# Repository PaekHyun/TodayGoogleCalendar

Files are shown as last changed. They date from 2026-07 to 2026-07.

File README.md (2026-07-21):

# Google Calendar → nanoESP32-C6 → WeAct 3.7" E-Paper

nanoESP32-C6에서 Google Calendar ICS를 가져와 WeAct 3.7인치 e-paper에 오늘 일정을 표시하는 프로젝트입니다.

## 사진

| 완성된 모습 | 동작 화면 |
|:---:|:---:|
| 완성된 모습 | 동작 화면 |

> 📸 사진을 추가하려면 `images/` 폴더에 이미지를 넣고 위 경로를 수정하세요.

## 하드웨어

| 부품 | 모델 |
|---|---|
| MCU | [nanoESP32-C6](https://github.com/wuxx/nanoESP32-C6) (MuseLab, ESP32-C6-WROOM-1) |
| 디스플레이 | WeAct 3.7" E-Paper Module (GDEY037T03, 240×416, UC8253) |
| 배터리 | 3.7V 리튬배터리 (10000mAh) |

## 배선도

```
nanoESP32-C6           WeAct 3.7" E-Paper
─────────────           ──────────────────
3V3            ──────→ VCC
GND            ──────→ GND
GPIO4  (MOSI)  ──────→ DIN (SDA/MOSI)
GPIO5  (SCK)   ──────→ CLK (SCK)
GPIO6  (CS)    ──────→ CS
GPIO7  (DC)    ──────→ DC
GPIO0  (RST)   ──────→ RST (RES)
GPIO1  (BUSY)  ──────→ BUSY
```

> **참고**: nanoESP32-C6는 ESP32-C6-WROOM-1 모듈 기반으로, GPIO 0~15, 18~21 등을 사용할 수 있습니다.
> GPIO12, GPIO13은 내부 플래시 접근용이므로 사용하지 마세요.

## 소프트웨어 설정

### 1. Arduino IDE 보드 설정

1. Arduino IDE → 파일 → 환경설정 → 추가 보드 매니저 URL:
   ```
   https://espressif.github.io/arduino-esp32/package_esp32_index.json
   ```
2. 툴 → 보드 → 보드 매니저 → `esp32` 검색 후 설치 (v2.0.8+)
3. 보드 선택: **ESP32C6 Dev Module**

### 2. 라이브러리 설치

Arduino IDE → 스케치 → 라이브러리 포함하기 → 라이브러리 관리:

| 라이브러리 | 작성자 | 용도 |
|---|---|---|
| **GxEPD2** | Jean-Marc Capello | E-Paper 디스플레이 드라이버 |
| **Adafruit GFX Library** | Adafruit | 그래픽 기반 라이브러리 |
| **U8g2_for_Adafruit_GFX** | Oliver | 한글 폰트 렌더링 |

### 3. WiFi 설정

`secrets.h` 파일을 열어 WiFi SSID와 비밀번호를 입력하세요:

```cpp
#define WIFI_SSID         "내WiFi이름"
#define WIFI_PASSWORD     "내WiFi비밀번호"
#define REFRESH_INTERVAL_MIN  30   // 새로고침 주기 (분)
```

### 4. 캘린더 설정

`TodayGoogleCalendar.ino` 상단의 `calendars[]` 배열에 Google Calendar 비공개 ICS URL을 입력하세요:

```cpp
CalendarInfo calendars[] = {
  { "가족", "https://calendar.google.com/calendar/ical/.../basic.ics" },
  { "시연", "https://calendar.google.com/calendar/ical/.../basic.ics" },
  { "정민", "https://calendar.google.com/calendar/ical/.../basic.ics" },
  { "현",   "https://calendar.google.com/calendar/ical/.../basic.ics" },
};
```

| 캘린더 인덱스 | 마커 |
|---|---|
| calendar[0] | ■ (꽉 찬 사각형) |
| calendar[1] | □ (빈 사각형) |
| calendar[2] | ▀ (위쪽 반) |
| calendar[3] | ▄ (아래쪽 반) |

### 5. 업로드

1. USB-C 케이블로 nanoESP32-C6 연결 (CH343 USB 포트 사용)
2. 올바른 포트 선택
3. 업로드 버튼 클릭

## 동작 흐름

```
부팅 → WiFi 연결(10초 타임아웃) → NTP 시간 동기화 → 
4개 캘린더 ICS 다운로드(5초 타임아웃) → 오늘 일정 파싱 → 
시간순 정렬 → E-Paper 표시 → WiFi OFF → E-Paper 전원차단 → 
GPIO 플로팅 방지 → 딥슬립 → N분 후 반복
```

## 절전 최적화

배터리 수명을 극대화하기 위해 다음 절전 기법이 적용되어 있습니다:

| 기법 | 설명 | 효과 |
|---|---|---|
| **딥슬립** | ESP32C6를 15μA 딥슬립 모드로 전환 | 대기 전류 ~99% 감소 |
| **WiFi 빠른 타임아웃** | 연결 10초, HTTP 5초로 단축 | 실패 시 낭비 전력 감소 |
| **WiFi 완전 해제** | 슬립 전 `WiFi.disconnect(true)` + `WIFI_OFF` | WiFi 모듈 누설 전류 차단 |
| **E-Paper RST LOW** | 슬립 중 RST 핀을 LOW로 전원 차단 | e-paper 누설 전류 감소 |
| **GPIO 풀다운** | 슬립 전 SPI/제어 핀 INPUT_PULLDOWN | 플로팅 핀 누설 전류 방지 |
| **전체 실패 시 즉시 슬립** | 4개 캘린더 모두 실패하면 바로 슬립 | 불필요한 WiFi 유지 방지 |

## 화면 레이아웃 (가로 모드 416×240)

```
┌──────────────────────────────────────────┐
│ 2026년 7월 15일 (수)                      │
│──────────────────────────────────────────│
│ 09:00-10:30  ■ 팀 미팅                    │
│              회의실 A                      │
│──────────────────────────────────────────│
│ 11:00-12:00  □ 시연 리허설                │
│──────────────────────────────────────────│
│ 종일         ▀ 생일 파티                   │
│──────────────────────────────────────────│
│ 14:00-15:30  ▄ 학원                       │
│                                          │
│                                          │
│ 11:28 갱신      ■가족 □시연 ▀정민 ▄현     │
└──────────────────────────────────────────┘
```

## 배터리 수명 (10000mAh 기준)

### 30분 주기 동작 사이클 전력 분석

| 구간 | 전류 | 시간 (초) | 비고 |
|---|---|---|---|
| WiFi 연결 | ~120mA | 5~8초 | AP 연결 + DHCP |
| NTP 동기화 | ~100mA | 2~3초 | |
| ICS 다운로드 ×4 | ~110mA | 10~20초 | HTTP GET ×4 |
| E-Paper 갱신 | ~30mA | 3~5초 | 화면 새로고침 |
| **활성 합계** | **~110mA** | **~30초** | |
| **딥슬립** | **~50~200μA** | **1790초** | e-paper 연결 누설포함 |

### 평균 소비 전류 계산

```
활성:  110mA × 30초  = 3,300 mA·s
슬립:  0.1mA × 1790초 =   179 mA·s  (딥슬립 100μA 가정)
─────────────────────────────────────
합계:  3,479 mA·s / 1800초 ≈ 1.93 mA (평균)
```

### 예상 수명

| 시나리오 | 딥슬립 전류 | 평균 소비 | 10000mAh 수명 |
|---|---|---|---|
| 🟢 이상적 | 15μA | ~1.85mA | **~225일 (7.5개월)** |
| 🟡 현실적 | 100μA | ~1.93mA | **~216일 (7.2개월)** |
| 🟠 보수적 | 500μA | ~2.14mA | **~195일 (6.5개월)** |
| 🔴 최악 | 1mA | ~2.83mA | **~147일 (4.9개월)** |

> 딥슬립 전류가 높아지는 주요 원인: e-paper 모듈의 풀업 저항 누설, WiFi 재시도, 배터리 보호 회로

### 현실적 결론

> **약 6~7개월** 동작 예상

단, 아래 요소를 고려하면 실제로는 **4~6개월** 정도로 보는 것이 안전합니다:

- 🔋 리튬배터리 방전 곡선 (3.7V → 3.0V 구간만 실사용 가능 → 유효 용량 ~85%)
- 📡 WiFi 연결 실패 시 재시도 (활성 시간 증가)
- 🌡️ 온도에 따른 배터리 효율 저하 (겨울철)
- ⚡ LDO 손실 (3.7V → 3.3V 변환 효율 ~90%)

### 💡 수명을 더 늘리려면

| 방법 | 효과 |
|---|---|
| 갱신 주기를 30분 → 1시간으로 | 수명 **약 1.8배** 연장 |
| ICS 다운로드 실패 시 즉시 슬립 ✅ | 불필요한 WiFi 유지 방지 (이미 적용) |
| E-Paper RST 핀으로 슬립 중 전원 차단 ✅ | 딥슬립 전류 50%↓ (이미 적용) |
| WiFi 연결 타임아웃 단축 (10초→5초) ✅ | 실패 시 낭비 감소 (이미 적용) |
| GPIO 플로팅 방지 ✅ | 누설 전류 감소 (이미 적용) |

## 문제 해결

| 증상 | 해결 방법 |
|---|---|
| 포트 인식 안 됨 | BOOT 버튼 누른 채 USB 연결 → 부트로더 모드 |
| WiFi 연결 실패 | SSID/비밀번호 확인, 2.4GHz 대역인지 확인 (5GHz 불가) |
| E-Paper 화면 안 나옴 | 배선 재확인, BUSY 핀 연결 상태 확인 |
| 시간 틀림 | NTP 서버 접근 가능한지 확인 |
| ICS 다운로드 실패 | ICS URL이 유효한지 브라우저에서 확인 |
| 배터리 빨리 닳음 | WiFi 타임아웃 확인, 딥슬립 진입 로그 확인 |

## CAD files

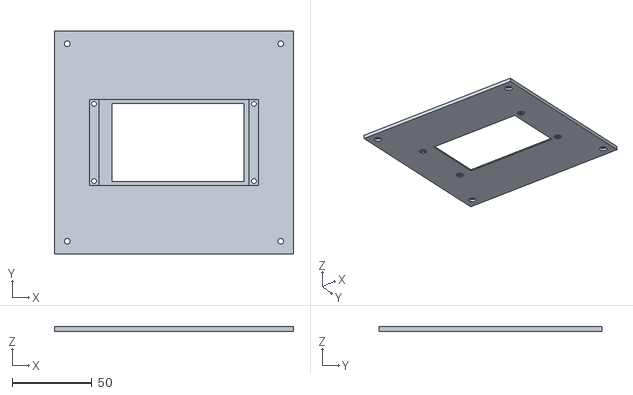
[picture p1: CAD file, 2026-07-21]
GoogleCalendarCase_FrontPanel.stl
150.0 x 140.0 x 3.00

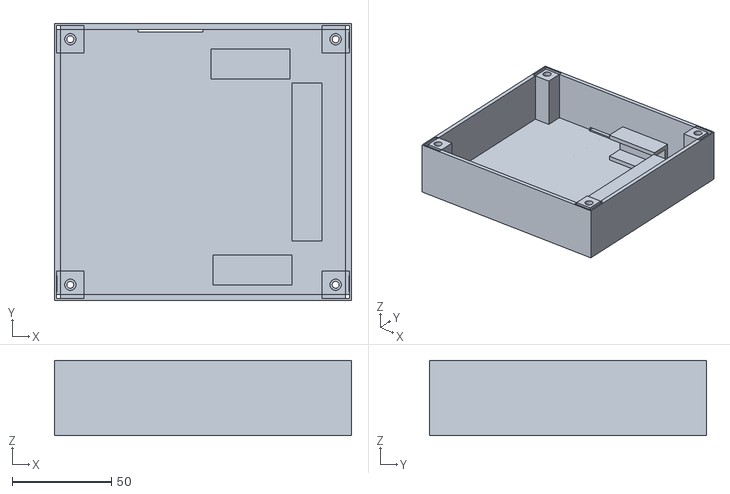
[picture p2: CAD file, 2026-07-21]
GoogleCalendar_RearPanel.stl
150.0 x 140.0 x 38.0

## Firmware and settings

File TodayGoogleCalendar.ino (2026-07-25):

/*
 * Google Calendar → nanoESP32-C6 → WeAct 3.7" E-Paper
 * 오늘 일정을 4개 캘린더에서 가져와 e-paper에 표시
 * 
 * 하드웨어 연결 (nanoESP32-C6 → e-paper):
 *   GPIO4  (MOSI) → DIN (SDA)
 *   GPIO5  (SCK)  → CLK (SCK)
 *   GPIO7  (DC)   → DC
 *   GPIO0  (RST)  → RST (RES)
 *   GPIO1  (BUSY) → BUSY
 *   GPIO6  (CS)   → CS
 *   3V3            → VCC
 *   GND            → GND
 * 
 * 필요 라이브러리:
 *   - GxEPD2 (by Jean-Marc Capello)
 *   - Adafruit_GFX
 *   - U8g2_for_Adafruit_GFX (by oliver)  ← 한글 폰트 지원
 * 
 * 보드 설정: ESP32C6 Dev Module (esp32 by Espressif v2.x+)
 * 보드: nanoESP32-C6 (MuseLab, https://github.com/wuxx/nanoESP32-C6)
 */

#define ENABLE_GxEPD2_GFX 0

#include <SPI.h>
#include <GxEPD2_BW.h>
#include <U8g2_for_Adafruit_GFX.h>  // 한글 폰트 지원

#include <WiFi.h>
#include <HTTPClient.h>
#include <time.h>

// ====== WiFi 설정 (secrets.h에서 수정) ======
#include "secrets.h"

// ====== 타임존 (KST = UTC+9) ======
const char* NTP_SERVER = "pool.ntp.org";
const long  TZ_OFFSET_SEC = 9 * 3600;   // UTC+9
const int   TZ_DST_SEC    = 0;

// ====== E-Paper 핀 설정 (nanoESP32-C6) ======
#define EPD_CS_PIN   6   // CS
#define EPD_DC_PIN   7   // DC
#define EPD_RST_PIN  0   // RST (RES)
#define EPD_BUSY_PIN 1   // BUSY
#define EPD_SCK_PIN  5   // SCK
#define EPD_MOSI_PIN 4   // MOSI (SDA/DIN)

#define VBAT_ADC_PIN        3      // 배터리 측정용 ADC 핀
#define VBAT_SAMPLES        8      // 평균낼 샘플 수
#define VBAT_DIVIDER_RATIO  2.0f   // 200kΩ : 200kΩ 분압


// [TestEPaper.ino 참고] 주석에 맞춰 핀 번호만 전달하여 객체 생성
GxEPD2_BW<GxEPD2_370_GDEY037T03, GxEPD2_370_GDEY037T03::HEIGHT> display(
  GxEPD2_370_GDEY037T03(EPD_CS_PIN, EPD_DC_PIN, EPD_RST_PIN, EPD_BUSY_PIN)
);

U8G2_FOR_ADAFRUIT_GFX u8g2Fonts; // 한글 폰트 렌더러

// ====== 캘린더 설정 ======
struct CalendarInfo {
  const char* name;
  const char* url;
};

CalendarInfo calendars[] = {
  { CAL_NAME_1, CAL_URL_1 },
  { CAL_NAME_2, CAL_URL_2 },
  { CAL_NAME_3, CAL_URL_3 },
  { CAL_NAME_4, CAL_URL_4 },
};
const int NUM_CALENDARS = sizeof(calendars) / sizeof(calendars[0]);

// ====== 일정 구조체 ======
struct Event {
  String summary;
  String location;
  int    startHour;
  int    startMin;
  int    endHour;
  int    endMin;
  bool   allDay;
  int    calIndex;
};

const int MAX_EVENTS = 30;
Event events[MAX_EVENTS];
int    eventCount = 0;

// ====== 캘린더 마커 그리기 ======
void drawCalMarker(int x, int y, int calIndex) {
  switch (calIndex % 4) {
    case 0: display.fillRect(x, y - 8, 6, 8, GxEPD_BLACK); break;  // ■ 꽉 찬 사각형
    case 1: display.drawRect(x, y - 8, 6, 8, GxEPD_BLACK); break;  // □ 빈 사각형
    case 2: display.fillRect(x, y - 8, 6, 4, GxEPD_BLACK); break;  // ▀ 위쪽 반
    case 3: display.fillRect(x, y - 4, 6, 4, GxEPD_BLACK); break;  // ▄ 아래쪽 반
  }
}

// ====== 배터리 전압 계산 ======
// VBAT --[200kΩ]-- ADC_PIN --[200kΩ]-- GND 형태의 분배 회로를 가정.
// analogReadMilliVolts()는 ESP32 코어에 내장된 ADC 보정(esp_adc_cal)을 사용하므로
// analogRead() 원시값을 직접 계산하는 것보다 정확합니다.
float readBatteryVoltage() {
  uint32_t sumMilliVolts = 0;
  for (int i = 0; i < VBAT_SAMPLES; i++) {
    sumMilliVolts += analogReadMilliVolts(VBAT_ADC_PIN);
    delay(1000);
  }
  float avgMilliVolts = (float)sumMilliVolts / VBAT_SAMPLES;
  float vbat = (avgMilliVolts / 1000.0f) * VBAT_DIVIDER_RATIO;

  Serial.printf("VBAT ADC 평균: %.1fmV -> 배터리 전압: %.2fV\n", avgMilliVolts, vbat);
  return vbat;
}

// ====== ICS 파싱 유틸리티 ======
void parseDateTime(const String& dtStr, int& year, int& month, int& day, int& hour, int& minute, bool& isAllDay) {
  isAllDay = false;
  year = 0; month = 0; day = 0; hour = 0; minute = 0;

  // 공백 및 앞뒤 잡음(개행문자 \r 등) 철저히 제거
  String cleanStr = dtStr;
  cleanStr.trim();
  cleanStr.replace("\r", "");
  cleanStr.replace("\n", "");

  if (cleanStr.length() == 8) {
    // 종일 일정 (예: 20260714)
    isAllDay = true;
    year  = cleanStr.substring(0, 4).toInt();
    month = cleanStr.substring(4, 6).toInt();
    day   = cleanStr.substring(6, 8).toInt();
  } 
  else if (cleanStr.length() >= 15) {
    // 일반 일정 (예: 20250210T073000Z)
    int tempYear  = cleanStr.substring(0, 4).toInt();
    int tempMonth = cleanStr.substring(4, 6).toInt();
    int tempDay   = cleanStr.substring(6, 8).toInt();
    int tempHour  = cleanStr.substring(9, 11).toInt();
    int tempMin   = cleanStr.substring(11, 13).toInt();

    if (cleanStr.endsWith("Z")) {
      struct tm t = {0};
      t.tm_year = tempYear - 1900;
      t.tm_mon  = tempMonth - 1;
      t.tm_mday = tempDay;
      t.tm_hour = tempHour + 9; // UTC -> KST (+9시간)
      t.tm_min  = tempMin;

      mktime(&t); 

      year   = t.tm_year + 1900;
      month  = t.tm_mon + 1;
      day    = t.tm_mday;
      hour   = t.tm_hour;
      minute = t.tm_min;
    } else {
      year   = tempYear;
      month  = tempMonth;
      day    = tempDay;
      hour   = tempHour;
      minute = tempMin;
    }
  }
}

int todayYear, todayMonth, todayDay;

void getToday() {
  struct tm timeinfo;
  if (!getLocalTime(&timeinfo)) {
    todayYear  = 2026; todayMonth = 7; todayDay = 14; // 폴백
    return;
  }
  todayYear  = timeinfo.tm_year + 1900;
  todayMonth = timeinfo.tm_mon + 1;
  todayDay   = timeinfo.tm_mday;
}

void parseICS(const String& icsData, int calIndex) {
  int pos = 0;
  while (pos < (int)icsData.length() && eventCount < MAX_EVENTS) {
    int veventStart = icsData.indexOf("BEGIN:VEVENT", pos);
    if (veventStart < 0) break;
    int veventEnd = icsData.indexOf("END:VEVENT", veventStart);
    if (veventEnd < 0) break;

    String vevent = icsData.substring(veventStart, veventEnd);


    String summary = "";
    String location = ""; 
    String dtStart = "";
    String dtEnd = "";

    // VEVENT 내부를 줄 단위로 분할하여 파싱
    int linePos = 0;
    while (linePos < (int)vevent.length()) {
      int nextLine = vevent.indexOf('\n', linePos);
      if (nextLine < 0) nextLine = vevent.length();
      
      String line = vevent.substring(linePos, nextLine);
      line.trim();
      line.replace("\r", ""); // \r 잔여물 제거

      if (line.startsWith("SUMMARY:")) {
        summary = line.substring(8);
      } else if (line.startsWith("LOCATION:")) {
        location = line.substring(9);
      } else if (line.startsWith("DTSTART")) {
        int colonIdx = line.indexOf(':');
        if (colonIdx >= 0) dtStart = line.substring(colonIdx + 1);
      } else if (line.startsWith("DTEND")) {
        int colonIdx = line.indexOf(':');
        if (colonIdx >= 0) dtEnd = line.substring(colonIdx + 1);
      }

      linePos = nextLine + 1;
    }

    // 앞뒤 공백 최종 트리밍
    summary.trim();
    location.trim();
    dtStart.trim();
    dtEnd.trim();

    int sYear, sMonth, sDay, sHour, sMin;
    bool sAllDay;
    parseDateTime(dtStart, sYear, sMonth, sDay, sHour, sMin, sAllDay);

    int eYear, eMonth, eDay, eHour, eMin;
    bool eAllDay;
    parseDateTime(dtEnd, eYear, eMonth, eDay, eHour, eMin, eAllDay);

    // [일정 판별 및 매칭]
    bool isToday = false;
    
    if (sAllDay) {
      if (sYear == todayYear && sMonth == todayMonth && sDay == todayDay) {
        isToday = true;
      }
      else if (sYear <= todayYear && eYear >= todayYear) {
        int todayScore = todayYear * 10000 + todayMonth * 100 + todayDay;
        int startScore = sYear * 10000 + sMonth * 100 + sDay;
        int endScore   = eYear * 10000 + eMonth * 100 + eDay;
        
        if (todayScore >= startScore && todayScore < endScore) {
          isToday = true;
        }
      }
    } else {
      if (sYear == todayYear && sMonth == todayMonth && sDay == todayDay) {
        isToday = true;
      }
    }

    if (isToday && summary.length() > 0) {
      events[eventCount].summary   = summary;
      events[eventCount].location  = location;
      events[eventCount].startHour = sHour;
      events[eventCount].startMin  = sMin;
      events[eventCount].endHour   = eHour;
      events[eventCount].endMin    = eMin;
      events[eventCount].allDay    = sAllDay;
      events[eventCount].calIndex  = calIndex;
      
      Serial.printf("  >> [추출성공] 캘린더[%d] | 일정: %s | 시작: %02d:%02d (종일: %s)\n", 
                    calIndex, summary.c_str(), sHour, sMin, sAllDay ? "예" : "아니오");

      eventCount++;

      delay(1000);
    } else {
      // 파싱 시도했으나 오늘 일정이 아닌 경우 디버그용 출력 (필요 시 주석 해제)
      // Serial.printf("  >> [패스] 일정: %s | 날짜: %04d-%02d-%02d\n", summary.c_str(), sYear, sMonth, sDay);
    }

    pos = veventEnd + 10;
  }
}

void sortEvents() {
  for (int i = 0; i < eventCount - 1; i++) {
    for (int j = i + 1; j < eventCount; j++) {
      int timeI = events[i].allDay ? -1 : events[i].startHour * 60 + events[i].startMin;
      int timeJ = events[j].allDay ? -1 : events[j].startHour * 60 + events[j].startMin;
      if (timeI > timeJ) {
        Event tmp = events[i];
        events[i] = events[j];
        events[j] = tmp;
      }
    }
  }
}



String fetchICS(const char* url) {
  HTTPClient http;
  String payload = "";

  http.setFollowRedirects(HTTPC_STRICT_FOLLOW_REDIRECTS);
  http.setTimeout(5000);
  http.setConnectTimeout(3000);

  if (http.begin(url)) {
    int httpCode = http.GET();
    if (httpCode == HTTP_CODE_OK) {
      payload = http.getString();
    } else {
      Serial.printf("[HTTP] GET → code: %d\n", httpCode);
    }
    http.end();
  } else {
    Serial.println("[HTTP] begin failed");
  }
  return payload;
}




// UTF-8 문자 경계를 지키면서, 주어진 픽셀 폭 안에 들어가도록 자르는 함수
String truncateToWidth(U8G2_FOR_ADAFRUIT_GFX& fonts, const String& text, int maxWidthPx) {
  if (fonts.getUTF8Width(text.c_str()) <= maxWidthPx) {
    return text;  // 안 잘라도 됨
  }

  String result = "";
  int i = 0;
  int len = text.length();

  while (i < len) {
    // 현재 문자의 바이트 길이 계산 (UTF-8 선두 바이트로 판별)
    unsigned char c = (unsigned char)text[i];
    int charLen = 1;
    if ((c & 0x80) == 0x00) charLen = 1;       // 0xxxxxxx: ASCII
    else if ((c & 0xE0) == 0xC0) charLen = 2;  // 110xxxxx
    else if ((c & 0xF0) == 0xE0) charLen = 3;  // 1110xxxx: 한글 대부분 여기
    else if ((c & 0xF8) == 0xF0) charLen = 4;  // 11110xxx

    if (i + charLen > len) break; // 깨진 데이터 방지

    String candidate = result + text.substring(i, i + charLen) + "..";
    if (fonts.getUTF8Width(candidate.c_str()) > maxWidthPx) {
      break; // "..." 붙였을 때 넘치면 여기서 멈춤
    }

    result += text.substring(i, i + charLen);
    i += charLen;
  }

  return result + "..";
}








// ====== E-Paper 표시 ======
void displayCalendar() {
  display.setRotation(1); // 가로 모드: 416 x 240
  display.setTextColor(GxEPD_BLACK);

  const int W = display.width();   // 416
  const int H = display.height(); // 240

  float vbatVoltage = readBatteryVoltage();

  display.setFullWindow();
  display.firstPage();
  do {
    display.fillScreen(GxEPD_WHITE);

    // ---- 헤더: 날짜 ----
    char dateStr[40];
    const char* dayNames[] = {"일", "월", "화", "수", "목", "금", "토"};
    struct tm timeinfo;
    getLocalTime(&timeinfo);
    snprintf(dateStr, sizeof(dateStr), "%d년 %d월 %d일 (%s)",
             todayYear, todayMonth, todayDay, dayNames[timeinfo.tm_wday]);

    u8g2Fonts.setFont(u8g2_font_unifont_t_korean2);
    u8g2Fonts.setCursor(8, 16);
    u8g2Fonts.print(dateStr);

    display.drawLine(0, 22, W, 22, GxEPD_BLACK);

    // ---- 일정 목록 ----
    int y = 38;
    const int lineHeight = 20;
    const int maxVisible = 8;

    if (eventCount == 0) {
      u8g2Fonts.setFont(u8g2_font_unifont_t_korean2);
      u8g2Fonts.setCursor(20, y + 10);
      u8g2Fonts.print("오늘 일정이 없습니다");
    } else {
      int showCount = min(eventCount, maxVisible);
      for (int i = 0; i < showCount; i++) {
        Event& ev = events[i];

        char timeBuf[20];
        if (ev.allDay) {
          snprintf(timeBuf, sizeof(timeBuf), "종일");
        } else {
          snprintf(timeBuf, sizeof(timeBuf), "%02d:%02d-%02d:%02d",
                   ev.startHour, ev.startMin, ev.endHour, ev.endMin);
        }


        u8g2Fonts.setFont(u8g2_font_unifont_t_korean2);

        // 시간 출력
        const int timeX = 4;
        u8g2Fonts.setCursor(timeX, y);
        u8g2Fonts.print(timeBuf);

        // 시간 문자열의 실제 폭 계산
        int timeWidth = u8g2Fonts.getUTF8Width(timeBuf);

        // 시간 뒤에 8픽셀 띄우고 마커 배치
        int markerX = timeX + timeWidth + 8;
        drawCalMarker(markerX, y, ev.calIndex);

        // 마커 뒤에 10픽셀 띄우고 제목 출력
        u8g2Fonts.setCursor(markerX + 10, y);

        int availWidth = W - (markerX + 10) - 4;
        String title = truncateToWidth(u8g2Fonts, ev.summary, availWidth);


        u8g2Fonts.print(title);



        if (ev.location.length() > 0 && y + 14 < H - 20) {
          u8g2Fonts.setCursor(92, y + 14);
          int availWidthLoc = W - 92 - 4;
          String loc = truncateToWidth(u8g2Fonts, ev.location, availWidthLoc);
          u8g2Fonts.print(loc);
          y += lineHeight + 14;
        } else {
          y += lineHeight;
        }

        if (i < showCount - 1 && y < H - 20) {
          // display.drawFastHLine(4, y - 4, W - 8, GxEPD_BLACK);
          display.drawFastHLine(4, y + 5, W - 8, GxEPD_BLACK);
        }
      }

      if (eventCount > maxVisible) {
        u8g2Fonts.setFont(u8g2_font_unifont_t_korean2);
        u8g2Fonts.setCursor(W - 80, H - 6);
        char moreBuf[20];
        snprintf(moreBuf, sizeof(moreBuf), "+%d개 더", eventCount - maxVisible);
        u8g2Fonts.print(moreBuf);
      }
    }

    // ---- 하단: 업데이트 시간 ----
    u8g2Fonts.setFont(u8g2_font_unifont_t_korean2);
    char updateStr[30];
    snprintf(updateStr, sizeof(updateStr), "%02d:%02d 갱신",
             timeinfo.tm_hour, timeinfo.tm_min);
    u8g2Fonts.setCursor(4, H - 4);
    u8g2Fonts.print(updateStr);

    // ---- 하단: 캘린더 범례 (배터리 전압 표시를 위해 한 줄 위로 이동) ----
    int legendX = W - 40 * NUM_CALENDARS;
    int legendY = H - 20;
    for (int i = 0; i < NUM_CALENDARS; i++) {
      drawCalMarker(legendX, legendY, i);
      u8g2Fonts.setCursor(legendX + 8, legendY);
      u8g2Fonts.print(calendars[i].name);
      legendX += 40;
    }

    // ---- 하단 오른쪽: 배터리 전압 ----
    char battBuf[16];
    snprintf(battBuf, sizeof(battBuf), "%.2fV", vbatVoltage);
    int battWidth = u8g2Fonts.getUTF8Width(battBuf);
    u8g2Fonts.setCursor(W - battWidth - 4, H - 4);
    u8g2Fonts.print(battBuf);

  } while (display.nextPage());
}

// ====== 에러 표시 ======
void displayError(const char* msg) {
  display.setRotation(1);
  display.setFullWindow();
  display.firstPage();
  do {
    display.fillScreen(GxEPD_WHITE);
    u8g2Fonts.setFont(u8g2_font_unifont_t_korean2);
    u8g2Fonts.setCursor(20, 60);
    u8g2Fonts.print("오류");
    u8g2Fonts.setCursor(20, 85);
    u8g2Fonts.print(msg);
  } while (display.nextPage());
}

// ====== WiFi 연결 ======
bool connectWiFi() {
  Serial.printf("WiFi 연결 중: %s", WIFI_SSID);
  WiFi.begin(WIFI_SSID, WIFI_PASSWORD);

  int attempts = 0;
  while (WiFi.status() != WL_CONNECTED && attempts < 20) {
    delay(500);
    Serial.print(".");
    attempts++;
  }
  Serial.println();

  if (WiFi.status() == WL_CONNECTED) {
    Serial.println("WiFi 연결됨!");
    Serial.print("IP: ");
    Serial.println(WiFi.localIP());
    return true;
  } else {
    Serial.println("WiFi 연결 실패!");
    WiFi.disconnect(true);
    WiFi.mode(WIFI_OFF);
    return false;
  }
}

// ====== NTP 시간 동기화 ======
bool syncTime() {
  configTime(TZ_OFFSET_SEC, TZ_DST_SEC, NTP_SERVER);
  struct tm timeinfo;
  int attempts = 0;
  while (!getLocalTime(&timeinfo) && attempts < 20) {
    delay(500);
    attempts++;
  }
  if (attempts >= 20) {
    Serial.println("NTP 시간 동기화 실패!");
    return false;
  }
  Serial.println("NTP 시간 동기화 완료");
  return true;
}

void powerOffWiFi() {
  WiFi.disconnect(true);
  WiFi.mode(WIFI_OFF);
  Serial.println("WiFi OFF (절전)");
}

void powerOffEPaper() {
  pinMode(EPD_RST_PIN, OUTPUT);
  digitalWrite(EPD_RST_PIN, LOW);
  Serial.println("E-Paper 전원 차단 (절전)");
}


// ====== 다음 정시(:00) 또는 정시반(:30)까지 남은 시간(초) 계산 ======
uint64_t secondsUntilNextHalfHour() {
  struct tm timeinfo;
  if (!getLocalTime(&timeinfo)) {
    // 시간 못 가져오면 기존처럼 REFRESH_INTERVAL_MIN 분 뒤로 폴백
    Serial.println("[슬립계산] 현재 시간 읽기 실패, 기본 간격 사용");
    return (uint64_t)REFRESH_INTERVAL_MIN * 60;
  }

  int curMin = timeinfo.tm_min;
  int curSec = timeinfo.tm_sec;

  int minutesToNext;
  if (curMin < 30) {
    minutesToNext = 30 - curMin;
  } else {
    minutesToNext = 60 - curMin;
  }

  uint64_t secondsToNext = (uint64_t)minutesToNext * 60 - curSec;

  // 너무 짧게 자는 것 방지 (예: 정확히 :00 근처에 깬 경우 몇 초 뒤 또 깨는 것 방지)
  const uint64_t MIN_SLEEP_SEC = 60; // 최소 1분은 자도록
  if (secondsToNext < MIN_SLEEP_SEC) {
    secondsToNext += 30 * 60; // 다음다음 정시/정시반으로 미룸
  }

  Serial.printf("[슬립계산] 현재 %02d:%02d:%02d → %llu초 뒤(%02d:%02d 기준) 깨어남\n",
                timeinfo.tm_hour, curMin, curSec,
                secondsToNext,
                (curMin < 30) ? timeinfo.tm_hour : (timeinfo.tm_hour + 1) % 24,
                (curMin < 30) ? 30 : 0);

  return secondsToNext;
}



// ====== 딥슬립 진입 ======
/*void enterDeepSleep() {
  Serial.printf("딥슬립 진입 (%d분 후 갱신)\n", REFRESH_INTERVAL_MIN);

  powerOffWiFi();
  powerOffEPaper();

  pinMode(EPD_MOSI_PIN, INPUT_PULLDOWN);  // MOSI (GPIO4)
  pinMode(EPD_SCK_PIN, INPUT_PULLDOWN);   // SCK  (GPIO5)
  pinMode(EPD_CS_PIN, INPUT_PULLDOWN);
  pinMode(EPD_DC_PIN, INPUT_PULLDOWN);
  pinMode(EPD_BUSY_PIN, INPUT_PULLDOWN);

  esp_sleep_enable_timer_wakeup((uint64_t)REFRESH_INTERVAL_MIN * 60 * 1000000ULL);
  esp_deep_sleep_start();
}*/

void enterDeepSleep() {
  uint64_t sleepSeconds = secondsUntilNextHalfHour();
  Serial.printf("딥슬립 진입 (%llu초 후 갱신, 정시/정시반 기준)\n", sleepSeconds);

  powerOffWiFi();
  powerOffEPaper();

  pinMode(EPD_MOSI_PIN, INPUT_PULLDOWN);
  pinMode(EPD_SCK_PIN, INPUT_PULLDOWN);
  pinMode(EPD_CS_PIN, INPUT_PULLDOWN);
  pinMode(EPD_DC_PIN, INPUT_PULLDOWN);
  pinMode(EPD_BUSY_PIN, INPUT_PULLDOWN);

  esp_sleep_enable_timer_wakeup(sleepSeconds * 1000000ULL);
  esp_deep_sleep_start();
}


void processEvent(const String& summary, const String& location,
                   const String& dtStart, const String& dtEnd, int calIndex) {
  if (eventCount >= MAX_EVENTS) return;

  int sYear, sMonth, sDay, sHour, sMin;
  bool sAllDay;
  parseDateTime(dtStart, sYear, sMonth, sDay, sHour, sMin, sAllDay);

  int eYear, eMonth, eDay, eHour, eMin;
  bool eAllDay;
  parseDateTime(dtEnd, eYear, eMonth, eDay, eHour, eMin, eAllDay);

  bool isToday = false;
  if (sAllDay) {
    if (sYear == todayYear && sMonth == todayMonth && sDay == todayDay) {
      isToday = true;
    } else if (sYear <= todayYear && eYear >= todayYear) {
      int todayScore = todayYear * 10000 + todayMonth * 100 + todayDay;
      int startScore = sYear * 10000 + sMonth * 100 + sDay;
      int endScore   = eYear * 10000 + eMonth * 100 + eDay;
      if (todayScore >= startScore && todayScore < endScore) isToday = true;
    }
  } else {
    if (sYear == todayYear && sMonth == todayMonth && sDay == todayDay) isToday = true;
  }

  if (isToday && summary.length() > 0) {
    events[eventCount].summary   = summary;
    events[eventCount].location  = location;
    events[eventCount].startHour = sHour;
    events[eventCount].startMin  = sMin;
    events[eventCount].endHour   = eHour;
    events[eventCount].endMin    = eMin;
    events[eventCount].allDay    = sAllDay;
    events[eventCount].calIndex  = calIndex;

    Serial.printf("  >> [추출성공] 캘린더[%d] | 일정: %s | 시작: %02d:%02d (종일: %s)\n",
                  calIndex, summary.c_str(), sHour, sMin, sAllDay ? "예" : "아니오");
    eventCount++;
  }
}

// String 통째로 만들지 않고, 스트림에서 한 줄씩 읽어 바로 파싱
bool fetchAndParseICS(const char* url, int calIndex) {
  HTTPClient http;
  http.setFollowRedirects(HTTPC_STRICT_FOLLOW_REDIRECTS);
  http.setTimeout(8000);
  http.setConnectTimeout(3000);

  if (!http.begin(url)) {
    Serial.println("[HTTP] begin failed");
    return false;
  }

  int httpCode = http.GET();
  if (httpCode != HTTP_CODE_OK) {
    Serial.printf("[HTTP] GET -> code: %d\n", httpCode);
    http.end();
    return false;
  }

  WiFiClient* stream = http.getStreamPtr();

  bool inEvent = false, sawEndCalendar = false;
  size_t totalBytes = 0;
  String summary, location, dtStart, dtEnd;

  unsigned long lastData = millis();
  while (http.connected() && (millis() - lastData < 8000)) {
    if (!stream->available()) { delay(2); continue; }

    String line = stream->readStringUntil('\n');
    lastData = millis();
    totalBytes += line.length();
    line.trim();
    line.replace("\r", "");

    if (line.startsWith("BEGIN:VEVENT")) {
      inEvent = true;
      summary = ""; location = ""; dtStart = ""; dtEnd = "";
    } else if (line.startsWith("END:VEVENT")) {
      if (inEvent) processEvent(summary, location, dtStart, dtEnd, calIndex);
      inEvent = false;
    } else if (inEvent) {
      if (line.startsWith("SUMMARY:")) summary = line.substring(8);
      else if (line.startsWith("LOCATION:")) location = line.substring(9);
      else if (line.startsWith("DTSTART")) {
        int c = line.indexOf(':'); if (c >= 0) dtStart = line.substring(c + 1);
      } else if (line.startsWith("DTEND")) {
        int c = line.indexOf(':'); if (c >= 0) dtEnd = line.substring(c + 1);
      }
    } else if (line.startsWith("END:VCALENDAR")) {
      sawEndCalendar = true;
    }
  }

  http.end();
  Serial.printf("  → %u bytes 스트리밍 처리 (여유힙: %u)\n", totalBytes, ESP.getFreeHeap());

  if (!sawEndCalendar) {
    Serial.println("  → END:VCALENDAR 못 봄 (스트림 끊김/타임아웃)");
    return false;
  }
  return true;
}



// ====== 메인 일정 갱신 ======
void refreshCalendar() {
  eventCount = 0;
  getToday();

  Serial.printf("오늘: %d-%02d-%02d\n", todayYear, todayMonth, todayDay);

  int failCount = 0;

  /*
  for (int i = 0; i < NUM_CALENDARS; i++) {
    Serial.printf("캘린더 '%s' 다운로드 중...\n", calendars[i].name);
    String icsData = fetchICS(calendars[i].url);
    if (icsData.length() > 0) {
      Serial.printf("  → %d bytes 수신\n", icsData.length());
      parseICS(icsData, i);
    } else {
      Serial.printf("  → 수신 실패\n");
      failCount++;
    }
  }
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
void loop() {
  // 딥슬립 사용으로 루프는 타지 않음
}

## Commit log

2026-07-13 Initial commit: Google Calendar e-paper display for XIAO ESP32C6
2026-07-13 Apply power-saving optimizations for battery life
    - WiFi connect timeout: 20s -> 10s
    - HTTP timeout: 10s -> 5s, connect timeout 3s
    - WiFi full disconnect before deep sleep (WIFI_OFF)
    - E-Paper RST pin LOW during sleep (cut leakage current)
    - GPIO pulldown on SPI/control pins during sleep
    - Immediate deep sleep on all-calendar download failure
    - Refresh interval configurable via secrets.h
    - Updated README with battery life estimates (10000mAh ~6-7 months)
2026-07-14 Fix: U8g2_for_Adafruit_GFX -> U8G2_FOR_ADAFRUIT_GFX (match library class name)
    [TodayGoogleCalendar.ino]
2026-07-14 Add 3D printed enclosure STL files
    [epaper_front_bezel.stl, epaper_rear_panel.stl]
2026-07-14 Redesign enclosure for breadboard + 12mm battery + 10mm e-paper
    - Front bezel: 150x140x3mm, 60x100mm display window, e-paper module pocket
    - Rear panel: 150x140x38mm deep, internal compartments:
    - Breadboard area (left/center, 90x134mm) with mounting posts
    - Battery compartment (right, 50x134mm) for 12mm thick 10000mAh
    - USB-C port cutout (front wall, centered)
    - M3 screw posts at 4 corners
    - E-paper support ledge at top
    - Internal divider with wiring gap
    [epaper_front_bezel.stl, epaper_rear_panel.stl]
2026-07-14 debug and esp32c6 normal board
2026-07-15 Replace XIAO ESP32C6 references with nanoESP32-C6 (MuseLab)
    [TodayGoogleCalendar.ino]
2026-07-15 Redesign STL: battery L-bracket supports + M3 insert nut/bolt fixation
    [epaper_front_bezel.stl, epaper_rear_panel.stl]
2026-07-15 Redesign battery L-bracket supports matching user sketch (side view cross-section)
    [epaper_rear_panel.stl]
2026-07-15 Split into 4 STL files: rear panel + left/right battery supports (3-sided U-bracket) + front bezel. M3 bolt+nut fixation.
    [battery_support_left.stl, battery_support_right.stl, epaper_rear_panel.stl]
2026-07-15 Fix: use boolean difference to actually cut holes in STL (bolt holes, insert nut holes, USB port, display window)
    [battery_support_left.stl, battery_support_right.stl, epaper_front_bezel.stl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]
2026-07-15 Swap battery/breadboard areas (battery=77mm, breadboard=65mm), divider half-height for wiring pass
    [battery_support_left.stl, battery_support_right.stl, epaper_rear_panel.stl]
2026-07-15 Fix e-paper dimensions to match GDEY037T03 spec: view 50x84.5mm, pocket 63x110mm. Add M3 bolt holes for e-paper module fixation.
    [epaper_front_bezel.stl, epaper_rear_panel.stl]
2026-07-15 Redesign rear panel: open-top structure with only corner posts + thin ledge frame for e-paper
    [epaper_rear_panel.stl]
2026-07-15 Remove floating ledge from rear panel (was hanging in mid-air in open-top design)
    [epaper_rear_panel.stl]
2026-07-15 Remove e-paper bolt holes from rear panel floor and front bezel (e-paper held by front pocket + front-rear bolts)
    [epaper_front_bezel.stl, epaper_rear_panel.stl]
2026-07-15 Fix battery support alignment: attach supports to wall/divider to prevent bolt hole overlap
    [epaper_rear_panel.stl]
2026-07-15 Restore e-paper bolt holes on front bezel (4x M3 with countersink)
    [epaper_front_bezel.stl]
2026-07-15 Implement battery voltage calculation and clean date input
    Add battery voltage reading functionality and improve date parsing.
2026-07-21 Update TodayGoogleCalendar.ino
    display init 리셋 타임수정
    [TodayGoogleCalendar.ino]
2026-07-21 Replace STL files with user-provided front and rear panel designs
    [GoogleCalendarCase_FrontPanel.stl, GoogleCalendar_RearPanel.stl, battery_support_left.stl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]
2026-07-25 display, calendar download 수정
    [TodayGoogleCalendar.ino]
2026-07-25 deep sleep mode 수정 / 매정시, 매정시30분 마다 꺠어나도록
    [TodayGoogleCalendar.ino]
